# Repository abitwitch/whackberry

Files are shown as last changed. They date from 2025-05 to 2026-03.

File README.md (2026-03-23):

# WhackberryPi
Disconnected Cyberdeck for password management.

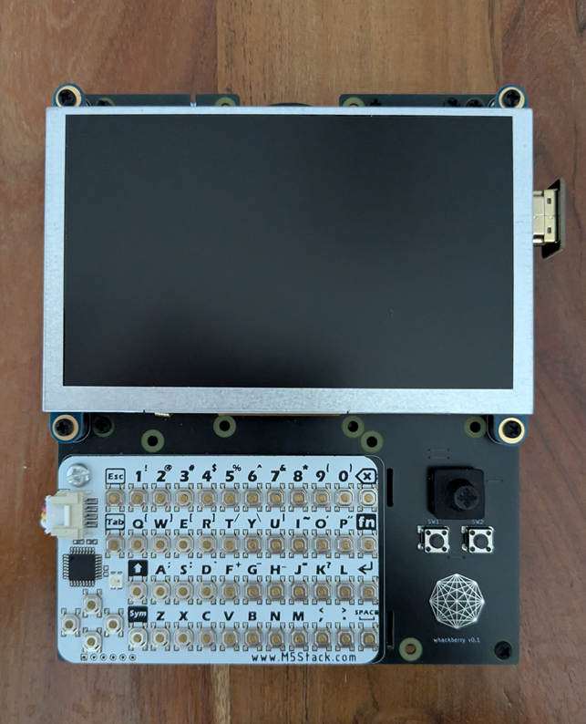
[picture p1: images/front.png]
Front of device

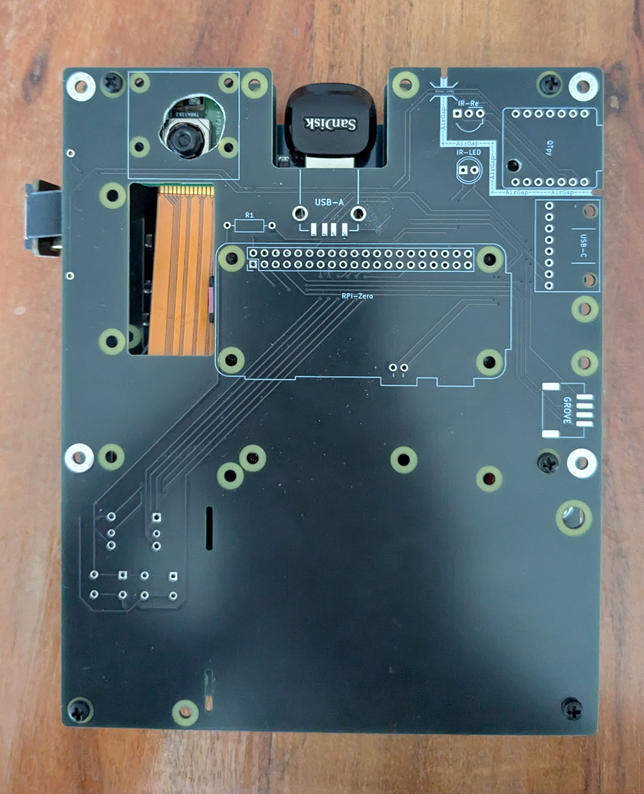
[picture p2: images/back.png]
Back of device


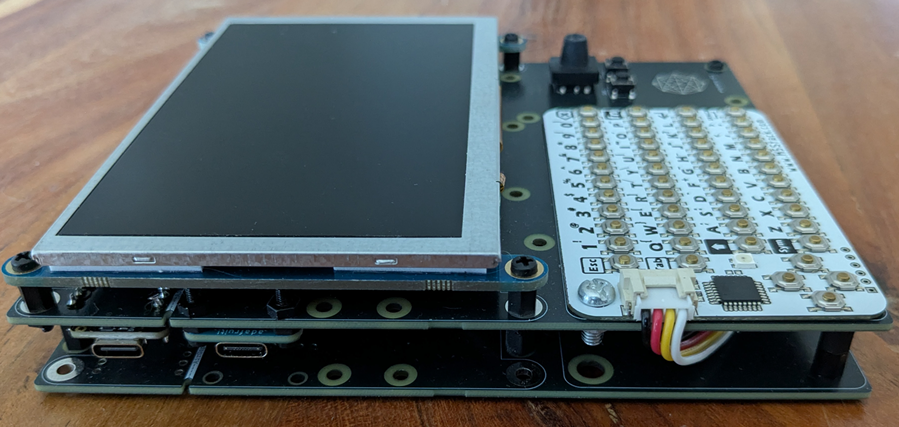
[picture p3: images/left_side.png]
Left side of device

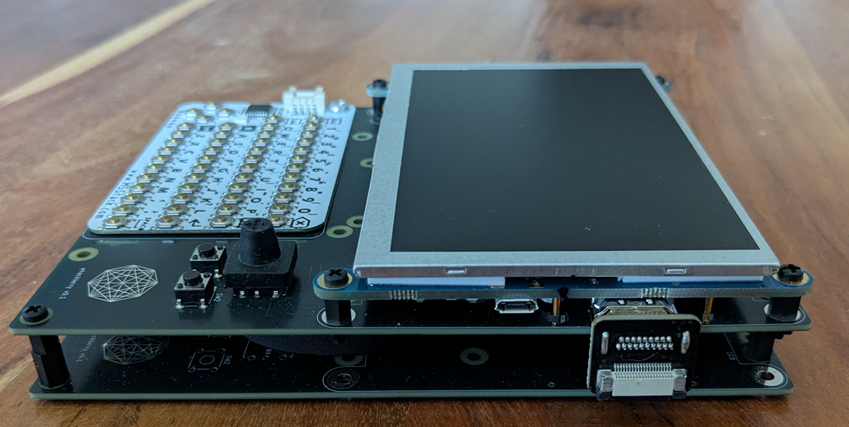
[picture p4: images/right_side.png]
Right side of device


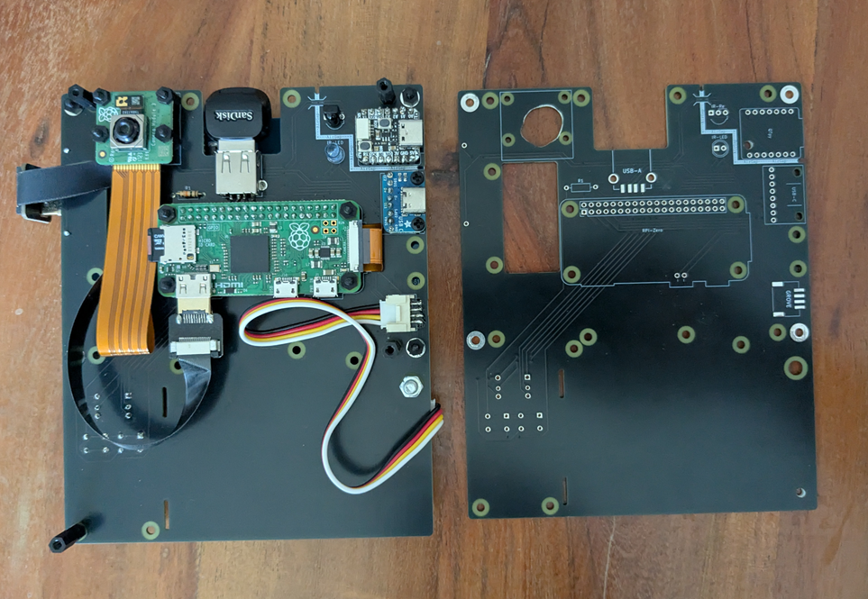
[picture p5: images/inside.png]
Inside of device


## Features:
- Disconnected computer (with display) with no wireless connectivity on any part of the device
- QWERTY keyboard with access to most standard symbols
- A mouse for navigating the OS in GUI mode
- A additional Micro SD card reader that can be used to create backups of passwords for storage in a secure secondary location
- A Camera to take pictures that are unable to reach the internet (useful for QR backup codes of 2FA apps)
- A disconnected microcontroller that is able to transmit data from the disconnected computer to another computer using a data diode

## How the data diode works:
1. The disconnected computer has a special command for transmitting data (`ir-sender`). This program can take standard input in bash.
2. The program encrypts the input. *NOTE* that the hardware only suport very weak and out-of-date encryption. Although it may provide a small layer of security, it should not be relied upon. This means anyone able to read the IR led blinking from inside the case, may be able to eventually decypt the messages. This seems like a low-level risk.
3. The program break the message into packets then into pulses and used the IR LED light transmit the password. Since there is no way to read messages from the LED, this is a one way communication. This is the data diode and it uses the "fire and forget" principle. This means errors in reading the message is possible. A check sum is part of the protocol to account for this possible error.
4. On the other side of the LED there is a IR Reciever. It is connected to a microcontroller that is completely disconnected* from the raspberry PI. The only way to communicate is over the air-gap via IR (one way).
*Note that the microcontroller is connected via power (5v and Ground). This allows the disconnected computer to be powered when the microcontroller is pluged into a computer. This does technically open the possibility of side channel attacks. 
5. The signal is recieved, decapsulated, combined, and de-crypted. The checksum is verified before decryption and the process will only continue if the checksum and decryption are successful.
6. When plugged into a computer, the air-gapped microcontroller acts as a keyboard and the message recieved is transmitted as keystrokes to the computer.

# Setup:
To set up a device, follow the instructions in each section of this readme from top to bottom. 

## Main Hardware
- Raspberry Pi Zero v1.3 [link](https://www.adafruit.com/product/2885)
- M5 CardKB (v1.1)
- HDMI 5" Display [link](https://www.adafruit.com/product/2232)
- Raspberry Pi Camera Module 3 [link](https://www.adafruit.com/product/5657)
- Infrared LED [link](https://www.adafruit.com/product/387)
- Infrared Receiver Sensor [link](https://www.adafruit.com/product/157)
- QT Py RP2040 [link](https://www.adafruit.com/product/4900)
- At least 1 micro CD card
- A Raspberry Pi with internet (for setup only)

## Supporting Hardware and PCB Mounting / cable accessories
- SMD Grove Female Header [link](https://www.mouser.ca/ProductDetail/Seeed-Studio/114020164?qs=7MVldsJ5Uayw%2FOfizq4F8w%3D%3D)
- USB Type-A Jack [link](https://www.mouser.ca/ProductDetail/Amphenol-FCI/87583-0010BHLF?qs=HGI6s9c03KdFNxR4%2F7F3Vg%3D%3D)
- HDMI cable [link1](https://www.adafruit.com/product/3552) [link2](https://www.adafruit.com/product/3549) [link3](https://www.adafruit.com/product/3561)
- Thru-hole 5-way Navigation switch (used as a mouse) [link](https://www.adafruit.com/product/504)
- 2x Buttons [link](https://www.adafruit.com/product/367)
- Pogo pins [link](https://www.adafruit.com/product/5381)
- Stand-off screws (the camera module may require a different size) [link](https://www.adafruit.com/product/3299)
- 1x 10k resistor [link](https://www.adafruit.com/product/2784)
- Male-male pin headers [link](https://www.adafruit.com/product/3009)
- USB Type C Breakout Board [link](https://www.adafruit.com/product/4090)
- SD card reader - SanDisk MobileMate USB 3.0 Reader [link](https://shop.sandisk.com/en-ca/products/accessories/memory-card-readers/sandisk-quickflow-microsd-usb-a-memory-card-reader?sku=SDDR-B731-GN6NN)
- DPDT switch [link](https://www.digikey.ca/en/products/detail/e-switch/EG2208/301963)
- One M4 nut and bolt (to attach CardKB)
- Solder and an soldering iron

## PCB
There PCB (Printed Circuit Board) design is included in this repository. This can be ordered online for a PCB manufacturer. If you want to forgo the case, you can order 2 boards and use the second with the one with standoffs to protect the device. 

**Schematic**
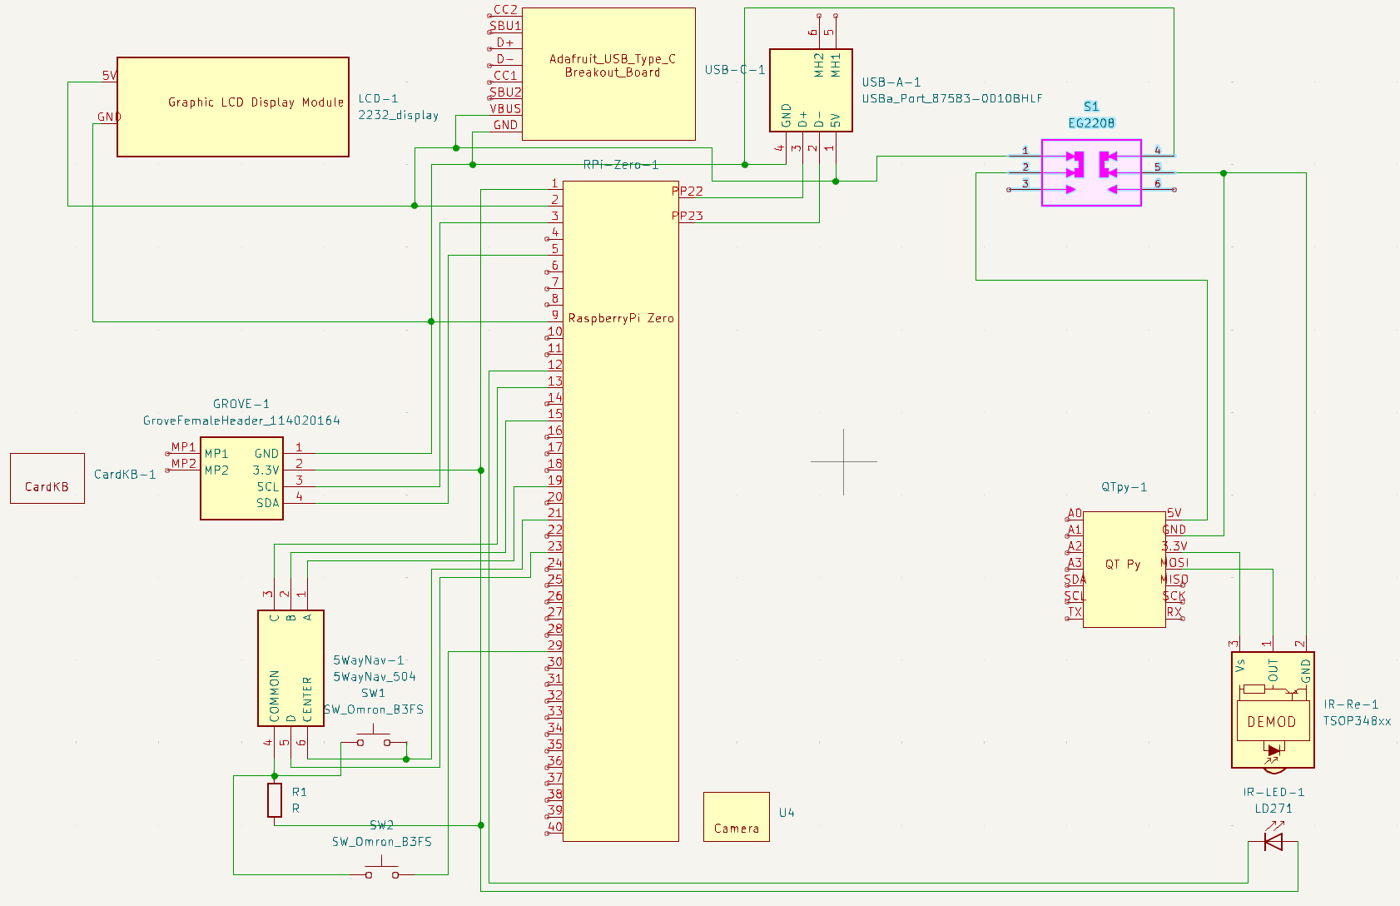
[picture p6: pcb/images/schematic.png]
Schematic showing all connections for the PCB Schematic of the PCB


**Design view**
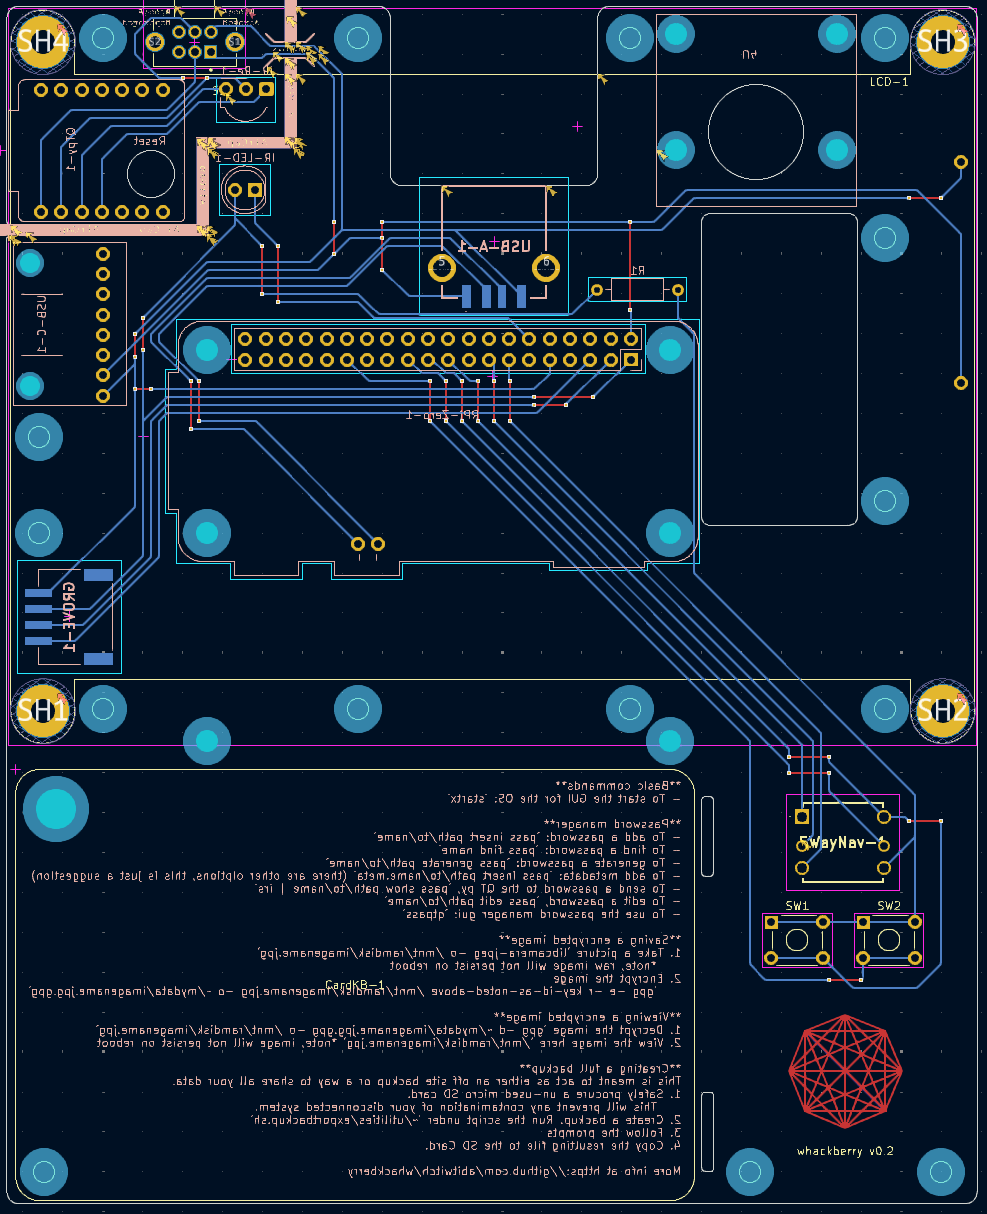
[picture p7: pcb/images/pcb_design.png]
Design view showing all the traces, cuts, and lables for the PCB Design of the PCB


**Front view**
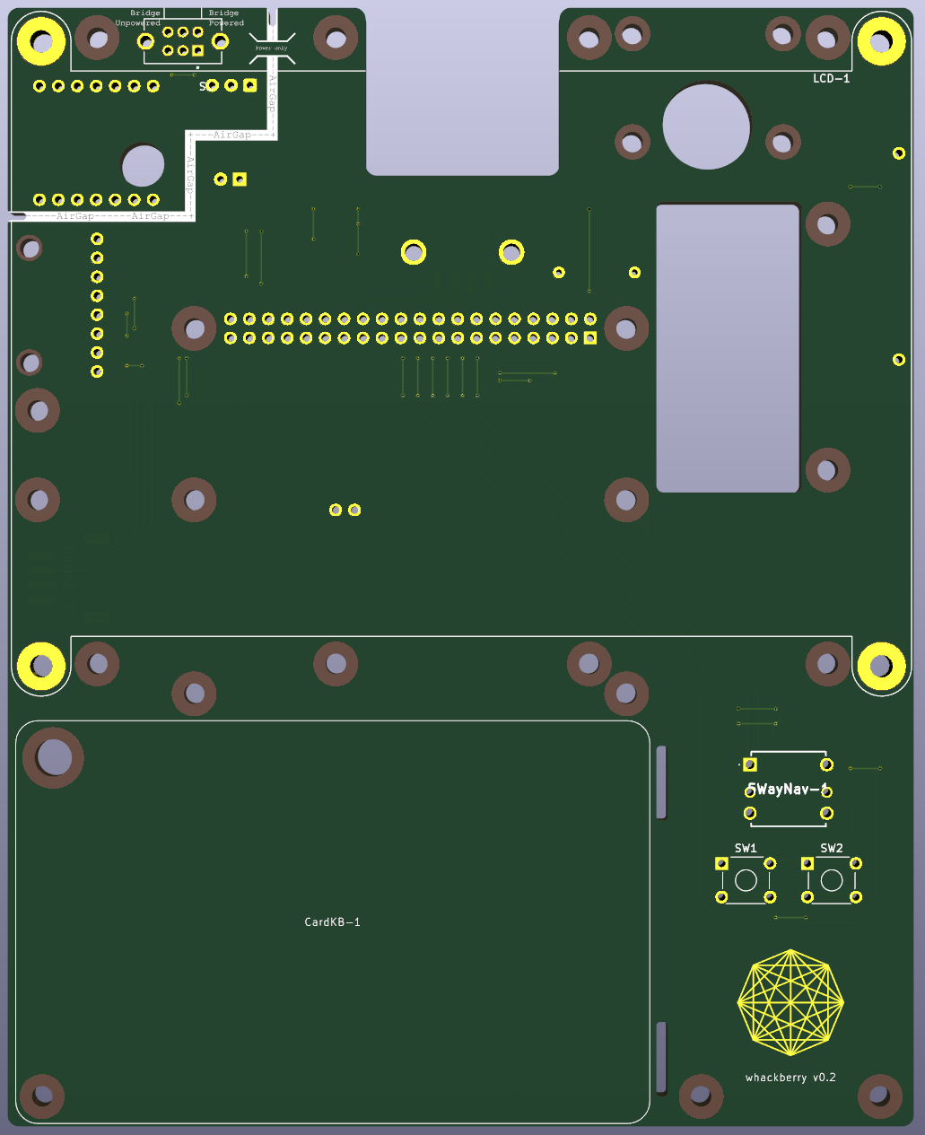
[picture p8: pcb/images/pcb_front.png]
Render of the front of the PCB Front of the PCB


**Back view**
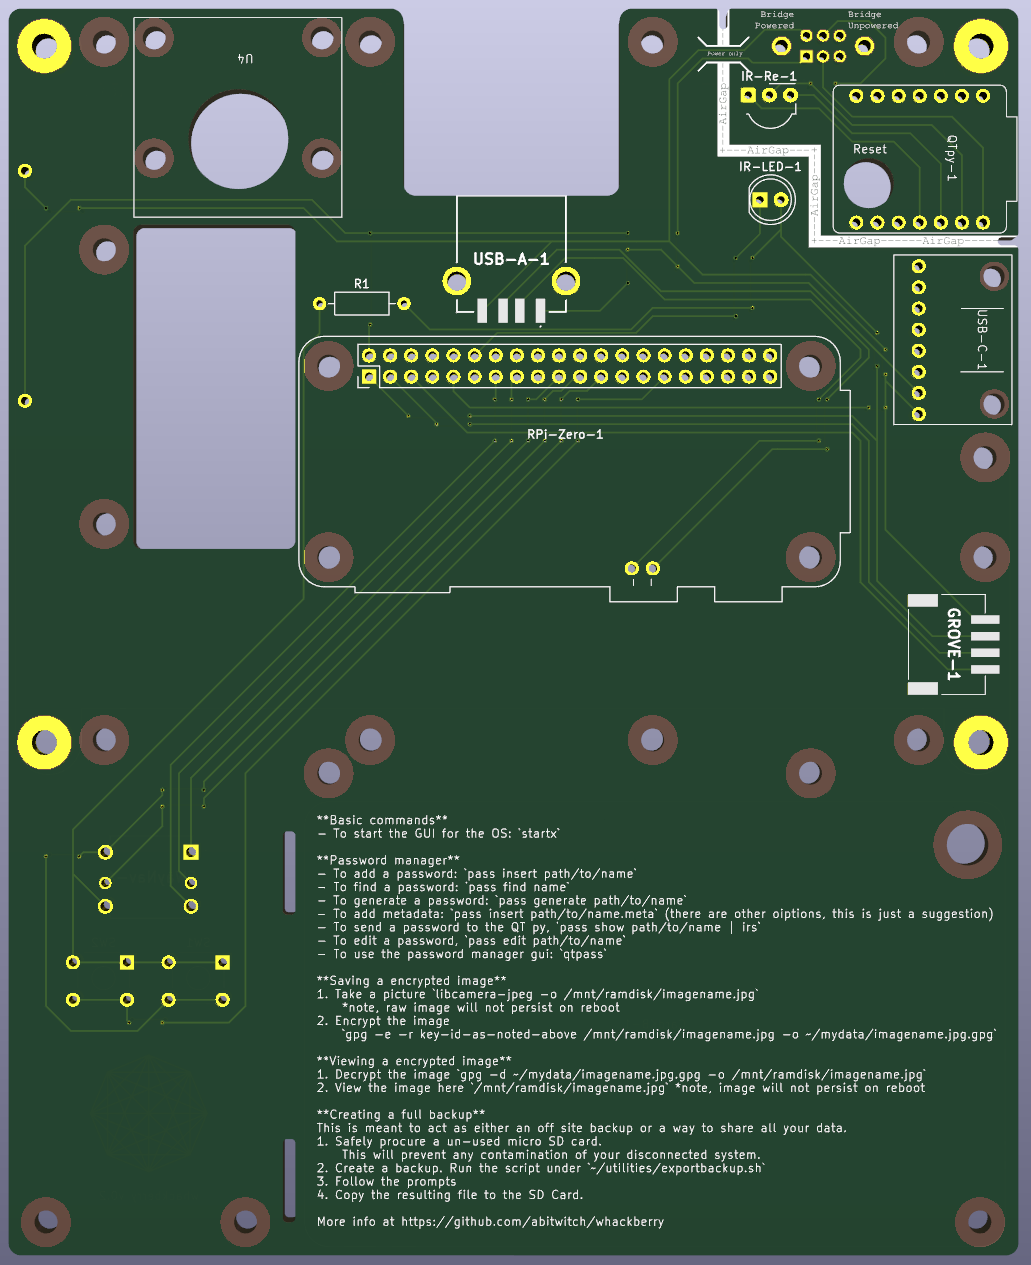
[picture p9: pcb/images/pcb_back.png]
Render of the back of the PCB Back of the PCB


## Assembly guide

This guide assumes you have some experince with soldering. Locational references (up, down, left, right) assume the PCB is upright with the logo facing you. The logo side is the front of the board, the other side is the back. 
### Prepare parts
1. Break the Male-male pin headers into 2 7 pin pieces and 1 8 pin piece
2. Solder the QTpy to the two 7 pin headers with the pins facing away from the side with the USB port on it.
3. Repeat the previous step for the Raspberry Pi Zero, and USB-c Breakout board. 
4. Break the POGO pins into 2 single pins and 1 pieces with 2 still attatched pins.

### Attach USB-c Breakout board
1. Use a M2.5 hex nut as a space between the USB-c breakout board and the main PCB, with the USB-c breakour board on the back of the main PCB. Secure the breakout board in place with more M2.5 nuts and screws
2. Clip of excess pin length from the pins of the USB-c breakout board headers and then solder the pins in place

### Attach QTpy
1. Place the QTpy in place on the back of the main PCB
2. Clip of excess pin length from the pins of the QTpy headers and then solder the pins in place

### Attach Raspberry Pi Zero
1. Solder the 2 attached pogo pins below the main headed pins in the Raspberry Pi Zero footprint. The pins should be facing the back of the board
2. Use 6mm long F-F hex standoffs and screws to attach the Raspberry Pi Zero fo the back of the main PCB. The pogo pins should be making contect with the Raspberry Pi Zero, and the main header pins should slightly protrude through the main PCB. 
3. Solder all the main header pins into place.

### Other soldered-in pieces
1. Solder the GROVE Female Header onto the back of the main PCB
2. Solder the USB Type-A Jack onto the back of the main PCB
3. Insert the 5-way nav switch on the front of the PCB and solder in the pins
4. Repeat step above for both buttons below the 5-wav nav switch
5. Insert the Resistor on the back of the main PCB, clip excess pin lenth, and solder into place
6. Repeat step above for the IR-Reciever and the IR LED

### Attach the camera module
1. The mounting holes on the camera module are slightly smaller than M2.5 screws. You will either need to largen the holes are buy different hardware.
2. Use 6mm long F-F hex standoffs to attatch the camera to the back of the main PCB

### Attach CardKB
1. Use the M4 nut and bolt to attach the CardKB to the front of the main PCB

### Cables
1. Connect the Camera module to the Raspberry Pi Zero
2. Connect the CardKB to the main PCB GROVE header
3. Use the DYI HDMI cable to connect the display to the Raspberry Pi Zero

### Protection plate
Only do this if you are not making a 3D printed case
1. Choose 4 or 5 well distributed, unused, and accessible mounting holes and insert into each a M2.5 10mm Screw into an unused PCB (with nothing else solder or attached to it)
2. To the back of each of the screws, screw on a 6mm long F-F hex standoff untill snug
3. To the still protruding screws, screw on a 8mm long F-F hex standoff untill snug
4. Place the this PCB on the main on being careful not to pitch any cables
5. Screw the two boards together with M2.5 4mm Screws into the standoffs

## Setup guide

### 1.00: SD card setup
This part can be done on any trusted computer connected to the internet
1. Download Official Raspberry Pi Imager
2. Select Legacy, 32-bit - Debian Bullseye (released 2024-10-22)
3. Flash the SD card and then access the files on the SD card
4. Set up the display
   1. Setup the display. Under `bootfs > config.txt` if accessing from a SD Card reader or `\boot\config.txt` if accessing from the OS, add the following lines (more info [here](https://learn.adafruit.com/adafruit-5-800x480-tft-hdmi-monitor-touchscreen-backpack/raspberry-pi-config))
       ```
       hdmi_group=2
       hdmi_mode=87
       hdmi_cvt=800 480 60 6 0 0 0
       hdmi_drive=1
       max_usb_current=1
       ```
   2. Enable i2c. In the same `config.txt` file, uncomment "dtparam=i2c_arm=on". Follow instructions [here](https://raspberrypi.stackexchange.com/questions/83457/can-i-enable-i2c-before-first-boot)

### 2.00: Configure the OS
I suggest doing the configuartion from another pi with internet. Plug the SD card into a internet-connected Raspberry Pi and boot it. Follow the commands to set up your account and apply any updates. You can use a less secure password if you want, the more import one will be the one you use when setting up a GPG key. Reboot the device.

#### 2.01: Enable i2c
1. In terminal type, `sudo raspi-config`
2. `Interface Options > I2C > Yes  (enable) > OK > Finish`

#### 2.02: Turn on boot to terminal by default (optional)
1. In terminal type, `sudo raspi-config`
2. `System Options > Boot / Auto login > Console Autologin > Finish`
3. In subsequent boots, if you want a GUI, enter `startx` into the terminal

#### 2.03: Updrade all apps / install new apps
1. In teminal: `sudo apt update && sudo apt full-upgrade`
2. Install password manager `sudo apt-get install pass`
3. Install password manager GUI `sudo apt-get install qtpass`
4. Install a game (helpful for using the system to build up randomness) `sudo apt-get install ninvaders`
5. Install 7z for secure ziped exports: 'sudo apt-get install p7zip-full'
6. Install circuit python: `sudo pip3 install adafruit-blinka`
7. Install PyUserInput for mouse: `sudo pip3 install PyUserInput pynput`
8. Install web3 for ethereum wallet generation: `sudo pip3 install web3`

#### 2.04: Install Electum
1. Go to [https://electrum.org/#download](https://electrum.org/#download)
2. `mkdir ~/electrum`, then `cd ~/electrum`
3. Follow the instructions for "Installation from Python sources" (tested with version 4.5.8)

#### 2.05: Copy Etherium wallet script
1. `mkdir ~/cryptowallet`
2. Copy `cryptowallet/gen-eth-wallet.py` from this repo to `~/cryptowallet/gen-eth-wallet.py` on the raspberry pi
3. `chmod +x gen-eth-wallet.py`

#### 2.06: CarKB setup
1. `mkdir ~/cardkb`, then `cd ~/cardkb`
2. Follow instructions [here](https://github.com/ian-antking/cardkb) (Note: add `sudo` to `modprobe uinput`)

#### 2.07: Camera Setup
- Just plug and play
- `libcamera-hello` to test
- `libcamera-jpeg -o /path/to/file.jpg` to take a picture

#### 2.08: Set up 5-way navi mouse
1. `mkdir ~/navmouse`, then `cd ~/navmouse`
2. Copy `navmouse/mouse.py` and `navmouse/navmouselauncher.sh` from this repo to `~/navmouse` on the raspberry pi
3. `chmod +x *`
4. 'sudo nano /etc/xdg/lxsession/LXDE-pi/autostart`
5. Add this line to the end of the file, then save and exit: `@/home/{name of user}/navmouse/navmouselauncher.sh`
TODO: Fix this section

#### 2.09: Infrared Transmitter
1. Create a RAM disk for storing output:
   1. Add `newramdisk  /mnt/ramdisk  tmpfs  rw,size=8M  0  0` to `/etc/fstab` (*Note, you must replace each set of spaces with a tab*)
2. Configuration
   1. `sudo nano /boot/config.txt`
   2. Add a line with `dtoverlay=gpio-ir-tx,gpio_pin=18` to the file, then save and exit
   3. `sudo nano /etc/modules`
   4. Add a line with `lirc_dev` to the file, then save and exit
3. `mkdir ~/ir-sender`
4. Copy `ir-protocol/ir-sender` from this repo to the folder `~/ir-sender`
5. Copy `ir-protocol/ir-sender-gui` from this repo to the folder `~/Desktop/ir-sender-gui`
6. `chmod +x ~/ir-sender`
7. `chmod +x ~/Desktop/ir-sender-gui`
8. Add these lines `~/.profile`
   ```
   if [ -d "$HOME/ir-sender" ] ; then
   PATH="$PATH:$HOME/ir-sender"
   fi
   ```
9. Generate new key: `ir-sender --genkey`
10. Copy the contents of the json and use it when setting up the Infrared Reciever
11. For ease of use, add an alias for `ir-sender`
   1. Edit `~/.bashrc`
   2. Add this line to the bottom: `alias irs=ir-sender`

#### 2.10: Infrared Reciever
This part of the device is on an isolated device that emulates a keyboard when plugged into the computer.
On a PC connected to the Pico
1. Download circuit python for the QTPy RP2040 ([link](https://circuitpython.org/board/adafruit_qtpy_rp2040/)) (I used CircuitPython 9.2.6)
2. Download the circuit python bundle ([link](https://github.com/adafruit/Adafruit_CircuitPython_Bundle/releases/tag/20250319)) (I used 'March 19, 2025 auto-release')
3. While holding down the `BOOT` button on the QTPy, connect it to the PC.
4. Copy the "uf2" file you downloaded in step 1 to the device. You should see `INDEX.HTM` and `INFO_UF2.TXT` there already. Wait for the device to reboot.
5. Unzip the folder from step 2 and copy the following folders and file to the `lib` folder of the QTPy.
   `adafruit_hid`, `adafruit_pixelbuf.mpy`, `neopixel.mpy`, `adafruit_rsa`, `adafruit_logging.mpy`, `adafruit_binascii`, `adafruit_hashlib` 
8. Copy the contents of the `ir-receiver-code.py` to `code.py`
9. Copy `boot.py` to `boot.py` at the top level of the QTPy
10. Create a new file at the top level called `private_key.json` and put the json contents in it generated when setting up the Infrared Transmitter

Optional: If you want a second reciever for any reason (for example, you don't want to plug the same reciever into every computer you need a password on), here's how to set up a secondary one.
1. Buy a secondary RP2040 device. This guide will assume you're using [the Waveshare RP2040-One](https://www.waveshare.com/product/rp2040-one.htm).
2. Solder on a IR (Infrared) Receiver (the same one listed earlier in this project). Attach GND to GND, V to 3.3V, and OUT to GP0. 
3. Follow the same steps above (for the main Infrared Reciever), with these minor changes
   1. In the `code.py` file, change `board.MOSI` to `board.GP0` and `board.NEOPIXEL` to `board.GP16`
   2. In the `boot.py` file, change `board.A0` to `board.GP15`
   3. Copy the `private_key.json` from the original RP2040 device to this one

#### 2.11: Copy over the utility scripts
1. `mkdir ~/utilities`
2. Copy `utilities/exportbackup.sh` from this repo to `~/utilities/exportbackup.sh` on the raspberry pi
3. Copy `utilities/importfromcsv.py` from this repo to `~/utilities/importfromcsv.py` on the raspberry pi
4. `sudo chmod +x ~/utilities/*`

#### 2.12: Test the system
1. Power down the raspberry pi you're using for setup. Move the SD card to the offline raspberry pi. 
2. Test the system to make sure all features work as expected

#### 2.12: Copy any passwords to the SD card
Copy password from any existing password managers to the SD Card (make sure to place them in a appropriate folder as not to mess up the OS on the SD Card).

### 3.00: Finish system init (offline) 
Only perform these steps when you're done setting up the device and ready to never connected to the internet again
1. If the SD card is still in the Raspberry Pi you were using for setup, move it to the offline Raspberry Pi Zero. 
2. Use system for 5-10 minutes to generate entopy (try `ninvaders`)
3. `mkdir ~/mydata`
4. Set up password manager
   1. Generate key
      1. `gpg --gen-key`
      2. Real name: user
      3. Email: [empty]
      4. `O` for okay
      5. Enter a password (this will be the master password for the password manager). Make sure it is a secure password and do not share it. 
      6. Note the id of the key. This will be a lond alphanumberic sequence right above "uid"
   2. Set key to never expire
      1. `gpg --edit-key key-id-as-noted-above`
      2. `expire`
      3. enter `0`
      4. `q` to quit (and `y` to save changes)
   2. `pass init key-id-as-noted-above`
5. Generate Bitcoin BTC wallet
   1. Start electrum with this command `~/electrum/Electrum-4.5.8/run_electrum`
   2. This application will run slowly. Be prepared to wait a few minutes between screens.
   3. Follow prompts and be sure to save the new seed to the password manager (`pass`). Using a password is recommended, you can generate and store one it `pass`, then copy it to the clipboard by using `pass -c {Folder/name}`
   4. In the "Recieve" tab, create a never expiring request and save the public address to `pass` as well. You can use this to send money to the wallet.
   5. Export the private keeys to `pass`
      1. Under "Wallet" > "Private keys", select "Export"
      2. Specify the file location to somewhere on `/mnt/ramdisk` (this way it will not presist on disk as plain text)
      3. Add a column to the CSV titled "BurntPrivKey", and set it to "No" for all rows
      4. Run `cat /mnt/ramdisk/{filename-of-exported-keys.csv} | pass insert {Folder/name} -m`
6. Generate Etherium ETH wallet
   1. Run the command `python3 ~/cryptowallet/gen-eth-wallet.py`
   2. Enter both the private key and the public key to the `pass` password manager

## Using the system
**Basic commands**
- To start the GUI for the OS: `startx`

**Password manager**
- To add a password: `pass insert path/to/name`
- To find a password: `pass find name`
- To generate a password: `pass generate path/to/name`
- To find a password: `pass find myaccount`
- To add metadata: `pass insert path/to/name.meta` (there are other oiptions, this is just a suggestion)
- To send a password to the QT py, `pass show path/to/name | irs`
- To edit a password, `pass edit path/to/name`
- To use the password manager gui: `qtpass`

**Saving a encrypted image**
1. Take a picture `libcamera-jpeg -o /mnt/ramdisk/imagename.jpg` *note, raw image will not persist on reboot
2. Encrypt the image `gpg -e -r key-id-as-noted-above /mnt/ramdisk/imagename.jpg -o ~/mydata/imagename.jpg.gpg`

**Viewing a encrypted image**
1. Decrypt the image `gpg -d ~/mydata/imagename.jpg.gpg -o /mnt/ramdisk/imagename.jpg`
2. View the image here `/mnt/ramdisk/imagename.jpg` *note, image will not persist on reboot

**Creating a full backup**
This is meant to act as either an off site backup or a way to share all your data.
1. Safely procure a un-used micro SD card. This will prevent any contamination of your disconnected system.
2. Create a backup. Run the script under `~/utilities/exportbackup.sh`
3. Follow the prompts. Note that with a lot of passwords, the "Exporting passwords" step can take a long time to run (last time was ~30 minutes for me).
4. Copy or move the resulting file to the SD Card.

**Import csv to password manager**
1. Modify the script here: `~/utilities/importfromcsv.py` to match the fields in the CSV from your password manager
2. Run `python3 ~/utilities/importfromcsv.py /path/to/passwords.csv`
3. After successfully importing the passwords, delete the csv `rm /path/to/passwords.csv`

## Sending recieving Bitcoin (btc)
You can send and recieve btc without exposing your private keys to the internet.

### Recieving:
1. Open Electrum
2. Go to the recieving tab and create a request. Make one of your "burnt" addresses it not being used. Send btc using any app to that address.

### Sending:
Option 1: signing a transaction (requires manual transcription)
1. On a computer connected to the internet
   1. Install Electrum and wait for it to sync
   2. Go to File > New/Restore
   3. Select "Import Bitcoin addresses or private keys"
   4. Enter the public addess (NOT the private keys!) from the Whackberry device (you can do that using this command: `echo bitcoin_public_address | irs`)
   5. Under the send tab, enter the address you want to send to, the amount, then click "Pay..."
   6. Set the transation fee and click "OK"
   7. Click the share button and "Copy to clipboard..." (paste in a text editor)
2. On the Whackberry
   1. Open Electrum
   2. On the top menu, "Tools" > "Load transation" > "From text"
   3. The camera will not work with the Electrum app, so you will have to manually copy the transation to the whackberry (make no mistakes, good luck).
   4. "Sign" the transation
   5. Click the share button and "Copy to clipboard..." (recommend pasting it somewhere like `/mnt/ramdisk/txn.txt`)
   6. Transfer that file back to the internet connected computer: `cat /mnt/ramdisk/txn.txt | irs` (you'll want to open a text editor on the internet connected computer to capture the contents of the file) 
3. On a computer connected to the internet
   1. In Electrum, on the top menu, "Tools" > "Load transation" > "From text"
   2. Paste in the transation contents you transfered from the whackberry.
   3. Click "Broadcast"
Option 2: Burning a Private key
1. Mark the private key as "burnt" on the Whackberry: `pass edit path/to/privatekeys`. I recommend labeling it in the Electrum GUI too (under the addresses tab)
2. Copy the ONLY THE BURNT private keys to a internet connected computer
   1. Test a command to ONLY get the burnt addresses: `pass show path/to/privatekeys | grep ,Yes` (Make 100% sure it's only outputing the private keys you want to burn)
   2. Copy the ket to the internet connected computer: ``pass show path/to/privatekeys | grep ,Yes | irs`
3. On the internet connected computer
   1. Follow steps 1.1 to 1.3 under "Option 1"
   2. Enter the private key
   3. Transfer all the bitcoin to your intended addresses. Keep in mind you can also transfer to other addresses on the Whackberry that are not yet burnt.

## Accessing cold wallets (online) 
1. Use `ir-sender` to send the target private key from the disconnected raspberry pi to a computer connect to the internet. Make sure to note any private keys or seeds being transfered. They are no longer totaly secure.
2. For Bitcion BTC:
   1. Download and install the Electrum application. Be very careful to download from the offical page (https://electrum.org/#download)[https://electrum.org/#download]
   2. Open the application and when prompted, select "Standard wallet" then "I already have a seed"
   3. Enter the seed for the Bitcoin BTC wallet.
   4. You can use the "Send" tab to send to any address. Start with a small amount to make sure everything is working.
3. For Etherium ETH:
   1. You can use any wallet that supports importing private keys to access the BTC. I'll include instructions for MetaMask Firefox Extension (v12.6.2) below.
   2. Go to MetaMask's site. Be sure it's the official source: [https://metamask.io/download/](https://metamask.io/download/)
   3. Download and lauch the extension
   4. Follow the propmts and select "create new wallet"
   5. Once on the main account page, click the account dropdown at the top of the screen
   6. Select "Add account or hardware wallet" then "Import account"
   7. Enter the private key for Etherium ETH.
   8. You can use the "Send" button to send to any address. Start with a small amount to make sure everything is working.

## Case
There is a 3D printable case included in this repository to help manage the cables and protect the devices. This case is yet to be printed and tested, so it likely we need to be altered and iterated. 

**Front of case**
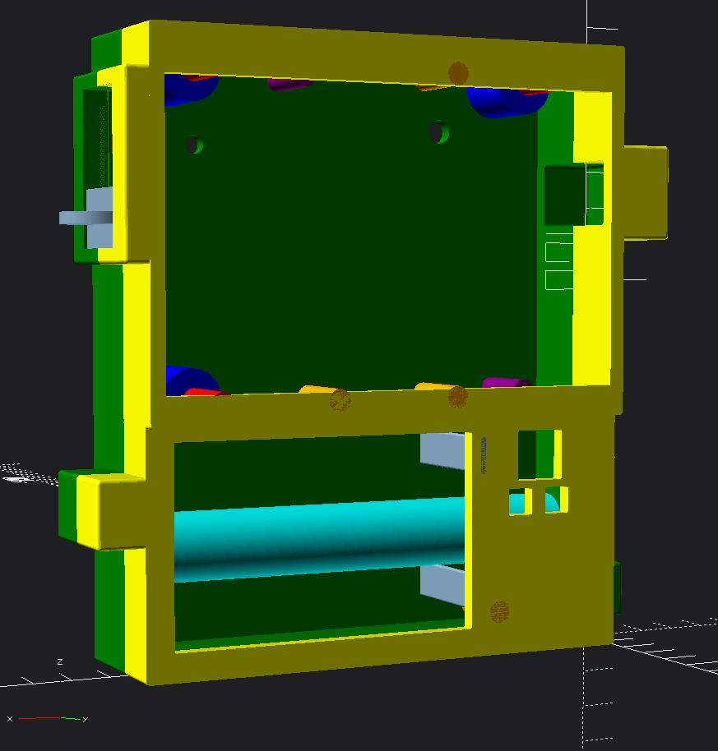
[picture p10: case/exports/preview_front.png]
3D render of the front of the case Front of case


**Back of case**
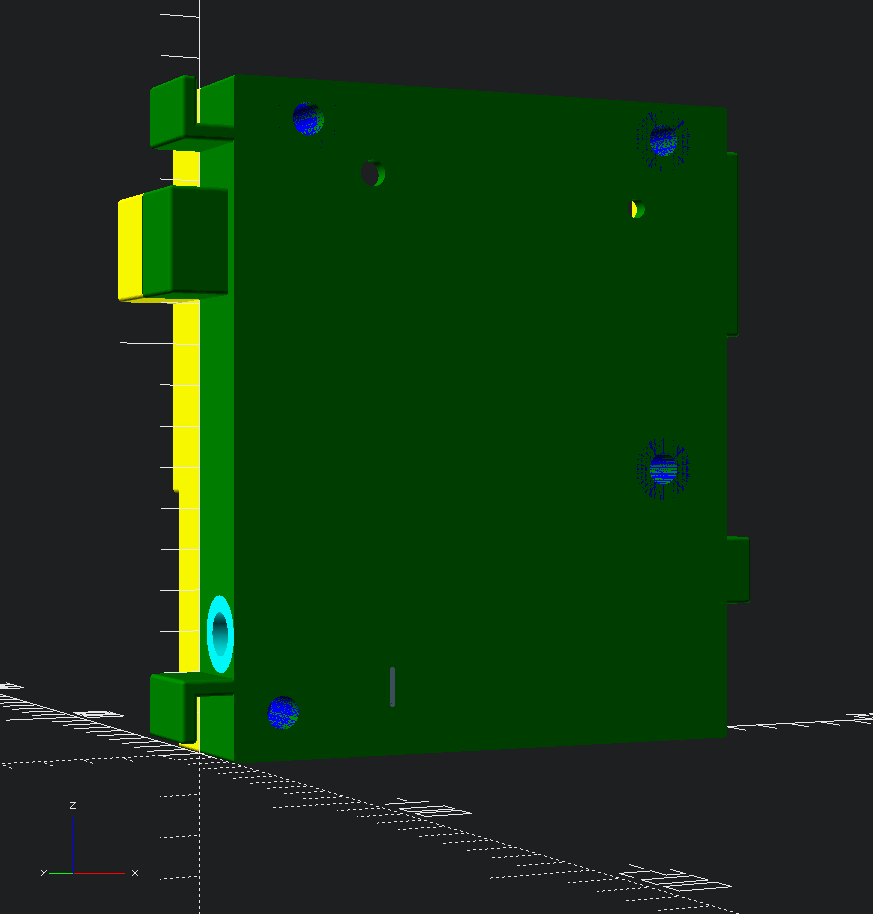
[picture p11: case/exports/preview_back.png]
3D render of the back of the case Back of case


## Trouble shooting
- Opening the camera causes the system to crash
   - This is likely a power issue to the camera. First try adding these two lines to the "/boot/config.txt" file; `over_voltage=2` and `force_turbo=1`. If the problem persists, lower the blacklight one the display by cutting the trace in between the two pads labeled "Open for -25mA" (more info [here](https://learn.adafruit.com/adafruit-5-800x480-tft-hdmi-monitor-touchscreen-backpack/pinouts)).

## Future work
- setup HID to act as a security key
- fix tempermental QTpy

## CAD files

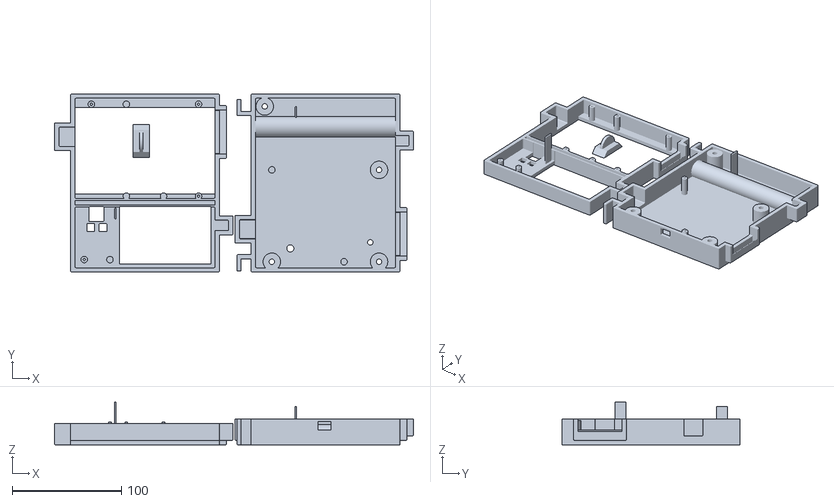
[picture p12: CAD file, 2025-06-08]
case/exports/case.stl
328.2 x 163.0 x 39.0

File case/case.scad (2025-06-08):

include <./modules/roundedcube.scad>
include <./modules/slider.scad>
include <./modules/screwhole.scad>
include <./modules/holepeg.scad>
//Note objects are anchored to the bottom right corner

//Vars (UNITS = mm)
global_thickness=4;
global_gap=3.5;
global_gap_tight=1.5;
global_nudge=0.01; //used as a tiny push to prevent two shapes from overlapping in digital rendering
global_pcb_thickness=1.4;
outer_upper_height=92+global_thickness+global_gap;
outer_upper_width=121+(2*global_thickness)+(2*global_gap);
outer_upper_depth=12+global_thickness+global_gap;
outer_upper_rounding=1;
outer_lower_height=56+global_thickness+global_gap;
outer_lower_width=outer_upper_width;
outer_lower_depth=8+global_thickness+global_gap;
outer_lower_rounding=outer_upper_rounding;
outer_rear_depth=16+global_thickness+global_gap;
keyboard_height=52.5;
keyboard_width=84;
keyboard_offset=[outer_lower_width-keyboard_width-global_thickness-global_gap,0,global_thickness+global_gap];
keyboard_rounding=0.5;
keyboard_bump_rounding=1;
keyboard_bump_height=10+global_thickness+global_gap;
keyboard_bump_width=5+global_thickness+global_gap+outer_lower_rounding+keyboard_bump_rounding;
keyboard_bump_depth=outer_lower_depth;
keyboard_bump_offset=[outer_lower_width-outer_lower_rounding-keyboard_bump_rounding,0,34];
keyboard_bump_hollow_offset=[keyboard_bump_offset[0]+global_thickness,keyboard_bump_offset[1]-global_nudge,keyboard_bump_offset[2]+global_thickness];
keyboard_support_front_width=1.4;
keyboard_support_front_depth=outer_lower_depth+outer_rear_depth-global_thickness;
keyboard_support_front_height=9.9;
keyboard_support_front_rounding=keyboard_support_front_width/2;
keyboard_support_front_offset=[32.8+global_thickness+global_gap,outer_lower_depth-keyboard_support_front_depth,41.1+global_thickness+global_gap];
keyboard_support_rear_width=keyboard_support_front_width;
keyboard_support_rear_depth=keyboard_support_front_depth;
keyboard_support_rear_height=keyboard_support_front_height;
keyboard_support_rear_rounding=keyboard_support_front_rounding;
keyboard_support_rear_offset=[32.8+global_thickness+global_gap,outer_lower_depth-keyboard_support_front_depth-global_thickness,4.1+global_thickness+global_gap];
mouse_nav_height=13.5;
mouse_nav_width=13.5;
mouse_nav_offset=[9.4+global_thickness+global_gap,0,38.8+global_thickness+global_gap];
mouse_nav_rounding=0.5;
mouse_left_height=7.2;
mouse_left_width=7.2;
mouse_left_offset=[18.5+global_thickness+global_gap,0,29.6+global_thickness+global_gap];
mouse_left_rounding=0.5;
mouse_right_height=mouse_left_height;
mouse_right_width=mouse_left_width;
mouse_right_offset=[7.3+global_thickness+global_gap,0,29.6+global_thickness+global_gap];
mouse_right_rounding=mouse_left_rounding;
display_height=75.9+(2*global_gap_tight);
display_width=121+(2*global_gap);
display_offset=[global_thickness,0,65.6+global_thickness+global_gap-global_gap_tight];
//display_rounding=0.1;
display_bump_rounding=1;
display_bump_height=18.5+(2*global_gap);
display_bump_width=11.2+global_gap+outer_upper_rounding+display_bump_rounding;
display_bump_depth=outer_upper_depth;
display_bump_offset=[-display_bump_width+outer_upper_rounding+display_bump_rounding,0,107-global_gap+global_thickness+global_gap];
display_bump_hollow_offset=[display_bump_offset[0]+global_thickness,display_bump_offset[1]-global_nudge,display_bump_offset[2]+global_thickness];
usbc_bump_rounding=1;
usbc_bump_height=41.2+(2*global_gap);
usbc_bump_width=3+global_gap+outer_upper_rounding+usbc_bump_rounding;
usbc_bump_depth=outer_upper_depth;
usbc_bump_offset=[outer_upper_width-outer_upper_rounding-usbc_bump_rounding,0,100-global_gap+global_thickness+global_gap];
usbc_bump_hollow_offset=[usbc_bump_offset[0]+(global_thickness*0),usbc_bump_offset[1]-global_nudge,usbc_bump_offset[2]+global_thickness]; //(global_thickness*0) to make is 2x thickness
slider_panel_width=20;
slider_panel_depth=6;
slider_panel_height=15;
slider_track_width=5;
slider_offset=[outer_upper_width,-(slider_panel_width+(2*slider_track_width))/2,usbc_bump_offset[2]+global_thickness];
slider_hollow_growth_factor=1.10;
slider_hollow_y_offset=-(((slider_panel_width*slider_hollow_growth_factor)+(2*slider_track_width*slider_hollow_growth_factor))-(slider_panel_width+(2*slider_track_width)))/2;
screwhole_radius=2.2/2;
screwhole_support_radius=3;
screwhole_nudge=global_nudge;
screwhole_offsets=[ //lateral offsets are to center of screwholes
  [5+global_thickness+global_gap,0,4+global_thickness+global_gap],
  [11.5+global_thickness+global_gap,0,146+global_thickness+global_gap],
  [109.5+global_thickness+global_gap,0,146+global_thickness+global_gap],
  [109.5+global_thickness+global_gap,0,62+global_thickness+global_gap],
];
//holepeg_support_height=outer_upper_depth;
holepeg_peg_height=global_pcb_thickness;
holepeg_peg_radius=1.2;
holepeg_support_radius=3;
holepeg_offsets=[ //lateral offsets are to center of screwholes
  [28.5+global_thickness+global_gap,0,4+global_thickness+global_gap],
  [43.5+global_thickness+global_gap,0,146+global_thickness+global_gap],
  [43.5+global_thickness+global_gap,0,62+global_thickness+global_gap],
  [77.5+global_thickness+global_gap,0,62+global_thickness+global_gap],
];
holepeg_rear_offsets=[ //lateral offsets are to center of screwholes
  [77.5+global_thickness+global_gap,0,146+global_thickness+global_gap],
  [11.5+global_thickness+global_gap,0,62+global_thickness+global_gap],
];
screwhole_counterbore_radius=4;
screwhole_counterbore_radius_primary=2.5;
pqty_reset_button_hole_radius=2.5;
pqty_reset_button_hole_offset=[101.5+global_thickness+global_gap,0,128.3+global_thickness+global_gap];
camera_hole_radius=3.25;
camera_hole_offset=[28.4+global_thickness+global_gap,0,133.8+global_thickness+global_gap];
sd_slot_offset=[53.8+global_thickness+global_gap,2.1,outer_upper_height+outer_lower_height-global_thickness-global_nudge];
sd_slot_width=12;
sd_slot_depth=8;
cable_hook_strut_length=13;
cable_hook_saddle_length=15;
cable_hook_rounding=1;
lower_cable_hook_offset=[0,-20,0];
upper_cable_hook_offset=[-outer_rear_depth,147,0];
screwdriver_slot_radius=(outer_rear_depth-(2*global_thickness)-(2*global_nudge)-global_pcb_thickness-global_gap)/2;
screwdriver_slot_offset=[0,outer_rear_depth-screwdriver_slot_radius-global_thickness-global_nudge,30];


//Layout Config
layout_printmode=0; //For design layout, set this to 0, for print layout, set to 1
layout_front_rotate=[270*layout_printmode,0,0];
layout_front_offset=[0,0,outer_upper_depth*layout_printmode];
layout_back_rotate=[90*layout_printmode,0,0];
layout_back_offset=[165*layout_printmode,(outer_upper_height+outer_lower_height)*layout_printmode,outer_rear_depth*layout_printmode];
layout_slider_rotate=[0,270*layout_printmode,0];
layout_slider_offset=[180*layout_printmode,120*layout_printmode,-slider_offset[0]*layout_printmode];


//slider
translate(layout_slider_offset)
rotate(layout_slider_rotate)
union () {
  translate(slider_offset)
  //translate([0,0,$t*slider_panel_height]) //animation
  rotate(90,[0,0,1])
  slider(slider_panel_width,slider_panel_depth,slider_panel_height,slider_track_width);
}
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

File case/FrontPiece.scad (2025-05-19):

include <./modules/roundedcube.scad>
include <./modules/slider.scad>
include <./modules/screwhole.scad>
include <./modules/holepeg.scad>
//Note objects are anchored to the bottom right corner

//Vars
global_thickness=0.2;
global_nudge=0.01; //used as a tiny push to prevent two shapes from overlapping in digital rendering
global_pcb_thickness=0.2;
outer_upper_height=8;
outer_upper_width=11;
outer_upper_depth=2;
outer_upper_rounding=0.25;
outer_lower_height=5;
outer_lower_width=outer_upper_width;
outer_lower_depth=1;
outer_lower_rounding=outer_upper_rounding;
keyboard_height=4;
keyboard_width=7;
keyboard_offset=[outer_lower_width-keyboard_width-0.5,0,0.5];
keyboard_rounding=0.5;
keyboard_bump_rounding=0.1;
keyboard_bump_height=1;
keyboard_bump_width=0.5+outer_lower_rounding+keyboard_bump_rounding;
keyboard_bump_depth=outer_lower_depth;
keyboard_bump_offset=[outer_lower_width-outer_lower_rounding-keyboard_bump_rounding,0,3];
keyboard_bump_hollow_offset=[keyboard_bump_offset[0]+global_thickness,keyboard_bump_offset[1]-global_nudge,keyboard_bump_offset[2]+global_thickness];
mouse_nav_height=1;
mouse_nav_width=1;
mouse_nav_offset=[1.5,0,3];
mouse_nav_rounding=0.1;
mouse_left_height=0.5;
mouse_left_width=0.5;
mouse_left_offset=[2.1,0,2.3];
mouse_left_rounding=0.1;
mouse_right_height=mouse_left_height;
mouse_right_width=mouse_left_width;
mouse_right_offset=[1.2,0,2.3];
mouse_right_rounding=mouse_left_rounding;
display_height=6;
display_width=10;
display_offset=[0.5,0,6];
//display_rounding=0.1;
display_bump_rounding=0.1;
display_bump_height=1.5;
display_bump_width=0.5+outer_upper_rounding+display_bump_rounding;
display_bump_depth=outer_upper_depth;
display_bump_offset=[-display_bump_width+outer_upper_rounding+display_bump_rounding,0,10];
display_bump_hollow_offset=[display_bump_offset[0]+global_thickness,display_bump_offset[1]-global_nudge,display_bump_offset[2]+global_thickness];
usbc_bump_rounding=0.1;
usbc_bump_height=4.5;
usbc_bump_width=0.25+outer_upper_rounding+usbc_bump_rounding;
usbc_bump_depth=outer_upper_depth;
usbc_bump_offset=[outer_upper_width-outer_upper_rounding-usbc_bump_rounding,0,7.5];
usbc_bump_hollow_offset=[usbc_bump_offset[0]+(global_thickness*0),usbc_bump_offset[1]-global_nudge,usbc_bump_offset[2]+global_thickness]; //(global_thickness*0) to make is 2x thickness
slider_panel_width=2;
slider_panel_depth=0.4;
slider_panel_height=2;
slider_track_width=0.5;
slider_offset=[outer_upper_width,-(slider_panel_width+(2*slider_track_width))/2,usbc_bump_offset[2]+global_thickness];
screwhole_radius=0.22/2;
screwhole_support_radius=screwhole_radius+global_thickness;
screwhole_nudge=global_nudge;
screwhole_offsets=[ //lateral offsets are to center of screwholes
  [0.5,0,0.5],
  [1.5,0,12.5],
  [9.5,0,12.5],
  [9.5,0,5.5],
];
//holepeg_support_height=outer_upper_depth; //TODO make dependant on location
holepeg_peg_height=global_pcb_thickness;
holepeg_peg_radius=0.1;
holepeg_support_radius=0.2;
holepeg_offsets=[ //lateral offsets are to center of screwholes
  [3,0,0.5],
  [4.5,0,12.5],
  [4.2,0,5.5],
  [7.5,0,5.5],
];

//slider
translate(slider_offset)
rotate(90,[0,0,1])
slider(slider_panel_width,slider_panel_depth,slider_panel_height,slider_track_width);

//front piece
translate([50,0,0]) //comment out line
color("yellow")
difference () {
    union () {
      //main shell upper shelf
      translate([0,0,outer_lower_height])
      roundedcube([outer_upper_width, outer_upper_depth, outer_upper_height], false, outer_upper_rounding, "y");
      //main shell lower shelf
      roundedcube([outer_lower_width, outer_lower_depth, outer_lower_height], false, outer_lower_rounding, "y"); 
      //main shell upper lower rounded corner bridge
      translate([0,0,outer_lower_height-outer_lower_rounding])
      cube([outer_lower_width, outer_lower_depth, outer_upper_rounding+outer_lower_rounding],false);
      //keyboard_bump
      translate(keyboard_bump_offset)
      roundedcube([keyboard_bump_width, outer_lower_depth, keyboard_bump_height], false, keyboard_bump_rounding, "ymax");
      //display bump
      translate(display_bump_offset)
      roundedcube([display_bump_width, outer_upper_depth, display_bump_height], false, display_bump_rounding, "ymax");
      //usbc bump
      translate(usbc_bump_offset)
      roundedcube([usbc_bump_width, outer_upper_depth, usbc_bump_height], false, usbc_bump_rounding, "ymax");
    }
    //main shell upper shelf hollow
    translate([0,0,outer_lower_height])
    translate([global_thickness,-global_nudge,global_thickness]) 
    roundedcube([outer_upper_width-(global_thickness*2), outer_upper_depth-global_thickness, outer_upper_height-(global_thickness*2)], false, outer_upper_rounding, "y");
    //main shell lower shelf hollow
    translate([global_thickness,-global_nudge,global_thickness]) 
    roundedcube([outer_lower_width-(global_thickness*2), outer_lower_depth-global_thickness, outer_lower_height-(global_thickness*2)], false, outer_lower_rounding, "y");
    //main shell upper lower rounded corner bridge hollow
    translate([0,0,outer_lower_height-(2*outer_lower_rounding)])
    translate([global_thickness,-global_nudge,0]) 
    cube([outer_lower_width-(global_thickness*2), outer_lower_depth-global_thickness, 2*(outer_upper_rounding+outer_lower_rounding)],false);
    //keyboard bump hollow
    translate(keyboard_bump_hollow_offset)
    translate([-global_thickness,0,0])
    roundedcube([keyboard_bump_width-global_thickness, outer_lower_depth-(global_thickness), keyboard_bump_height-(2*global_thickness)], false, keyboard_bump_rounding, "ymax");
    //display bump hollow
    translate(display_bump_hollow_offset)
    roundedcube([display_bump_width-(global_thickness)+global_nudge, outer_upper_depth-(global_thickness), display_bump_height-(2*global_thickness)], false, display_bump_rounding, "ymax");
    //usbc bump hollow
    translate(usbc_bump_hollow_offset)
    roundedcube([usbc_bump_width-(global_thickness), outer_upper_depth-(global_thickness), usbc_bump_height-(2*global_thickness)], false, usbc_bump_rounding, "ymax");
    //Keyboard hole
    translate(keyboard_offset) 
    roundedcube([keyboard_width, outer_lower_depth*2, keyboard_height], false, keyboard_rounding, "y");
    //Mouse nav hole
    translate(mouse_nav_offset) 
    roundedcube([mouse_nav_width, outer_lower_depth*2, mouse_nav_height], false, mouse_nav_rounding, "y");
    //Mouse left button hole
    translate(mouse_left_offset) 
    roundedcube([mouse_left_width, outer_lower_depth*2, mouse_left_height], false, mouse_left_rounding, "y");
    //Mouse right button hole
    translate(mouse_right_offset) 
    roundedcube([mouse_right_width, outer_lower_depth*2, mouse_right_height], false, mouse_right_rounding, "y");
    //Display hole
    translate(display_offset) 
    cube([display_width, outer_upper_depth*2, display_height], false);
    //TODO add slider
}

//front screwholes
color("red")
for (i = [ 0 : len(screwhole_offsets)-1 ]) {
  if (holepeg_offsets[i][2]<outer_lower_height) {
    screwhole_support_height=outer_lower_depth;
    screwhole_height=screwhole_support_height-(global_thickness);
    translate(screwhole_offsets[i])
    screwhole(screwhole_support_height-global_nudge, screwhole_height, screwhole_support_radius, screwhole_radius, screwhole_nudge);
  } else {
    screwhole_support_height=outer_upper_depth;
    screwhole_height=screwhole_support_height-(global_thickness*4);
    translate(screwhole_offsets[i])
    screwhole(screwhole_support_height-global_nudge, screwhole_height, screwhole_support_radius, screwhole_radius, screwhole_nudge);
  }
}
//front holepegs
color("orange")
for (i = [ 0 : len(holepeg_offsets)-1 ]) {
  if (holepeg_offsets[i][2]<outer_lower_height) {
    holepeg_support_height=outer_lower_depth;
    translate(holepeg_offsets[i])
    translate([0,-holepeg_peg_height,0])
    holepeg(holepeg_support_height, holepeg_peg_height, holepeg_support_radius, holepeg_peg_radius);
  } else {
    holepeg_support_height=outer_upper_depth;
    translate(holepeg_offsets[i])
    translate([0,-holepeg_peg_height,0])
    holepeg(holepeg_support_height, holepeg_peg_height, holepeg_support_radius, holepeg_peg_radius);
  }
}






outer_rear_depth=2;
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

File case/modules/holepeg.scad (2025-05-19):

module holepeg(support_height, peg_height, support_radius, peg_radius){
  rotate(90,[-1,0,0])
  union () {
    cylinder(h=peg_height, r1=peg_radius, r2=peg_radius, center=false, $fn=256);
    translate([0,0,peg_height])
    cylinder(h=support_height, r1=support_radius, r2=support_radius, center=false, $fn=256);
  }
}

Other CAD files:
case/modules/screwhole.scad
case/modules/roundedcube.scad
case/modules/slider.scad

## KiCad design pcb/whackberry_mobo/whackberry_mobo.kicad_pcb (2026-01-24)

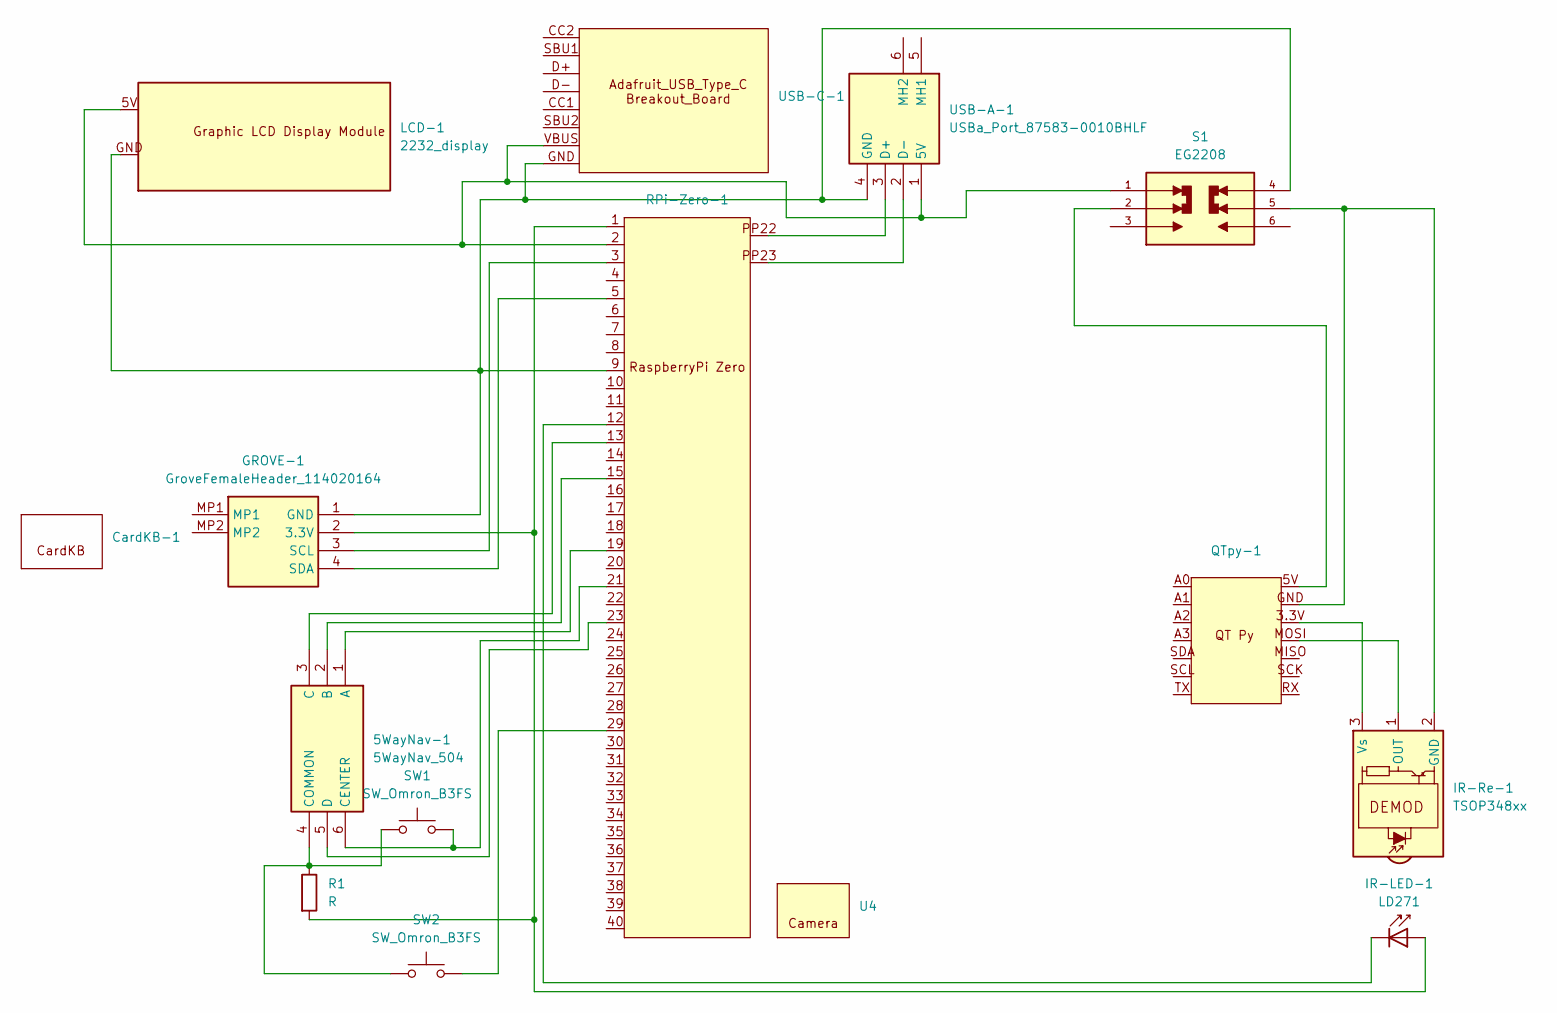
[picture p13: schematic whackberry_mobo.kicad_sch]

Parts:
5WayNav-1: 5WayNav_504; Mouser Part Number 485-504
CardKB-1: CardKB
GROVE-1: GroveFemaleHeader_114020164; Mouser Part Number 713-114020164
IR-LED-1: LD271; LED_D5.0mm_IRGrey
IR-Re-1: TSOP348xx; Vishay_MOLD-3Pin
LCD-1: 2232_display; Display_MODULE_2232; PARTREV N/A
QTpy-1: QT_Py
R1: R; R_Axial_DIN0207_L6.3mm_D2.5mm_P10.16mm_Horizontal
RPi-Zero-1: Modified_Raspberry_Pi_Zero_Socketed_THT_FaceDown_MountingHo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
S1: EG2208; SW_EG2208; PARTREV C
SW1, SW2: SW_Omron_B3FS; SW_TH_Tactile_Omron_B3F-10xx
U4: Camera
USB-A-1: USBa_Port_87583-0010BHLF; USBa_Port_875830010BHLF; Manufacturer_Part_Number 87583-0010BHLF
USB-C-1: Adafruit_USB_Type_C_Breakout_Board

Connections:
unnamed: 5WayNav-1.1 (A), RPi-Zero-1.19
unnamed: 5WayNav-1.2 (B), RPi-Zero-1.15
unnamed: 5WayNav-1.3 (C), RPi-Zero-1.13
unnamed: 5WayNav-1.6 (CENTER), RPi-Zero-1.21, SW1.2
unnamed: 5WayNav-1.4 (COMMON), R1.1, SW1.1, SW2.1
unnamed: 5WayNav-1.5 (D), RPi-Zero-1.23
unnamed: GROVE-1.2 (3.3V), IR-LED-1.2 (A), R1.2, RPi-Zero-1.1
unnamed: GROVE-1.1 (GND), LCD-1.GND, RPi-Zero-1.9, S1.4, USB-A-1.4 (GND), USB-C-1.GND
unnamed: GROVE-1.3 (SCL), RPi-Zero-1.3
unnamed: GROVE-1.4 (SDA), RPi-Zero-1.5
unnamed: IR-LED-1.1 (K), RPi-Zero-1.12
unnamed: IR-Re-1.2 (GND), QTpy-1.GND, S1.5
unnamed: IR-Re-1.1 (OUT), QTpy-1.MOSI
unnamed: IR-Re-1.3 (Vs), QTpy-1.3.3V
unnamed: QTpy-1.5V, S1.2
unnamed: RPi-Zero-1.29, SW2.2
unnamed: LCD-1.5V, RPi-Zero-1.2, S1.1, USB-A-1.1 (5V), USB-C-1.VBUS
unnamed: RPi-Zero-1.PP22, USB-A-1.3 (D+)
unnamed: RPi-Zero-1.PP23, USB-A-1.2 (D-)

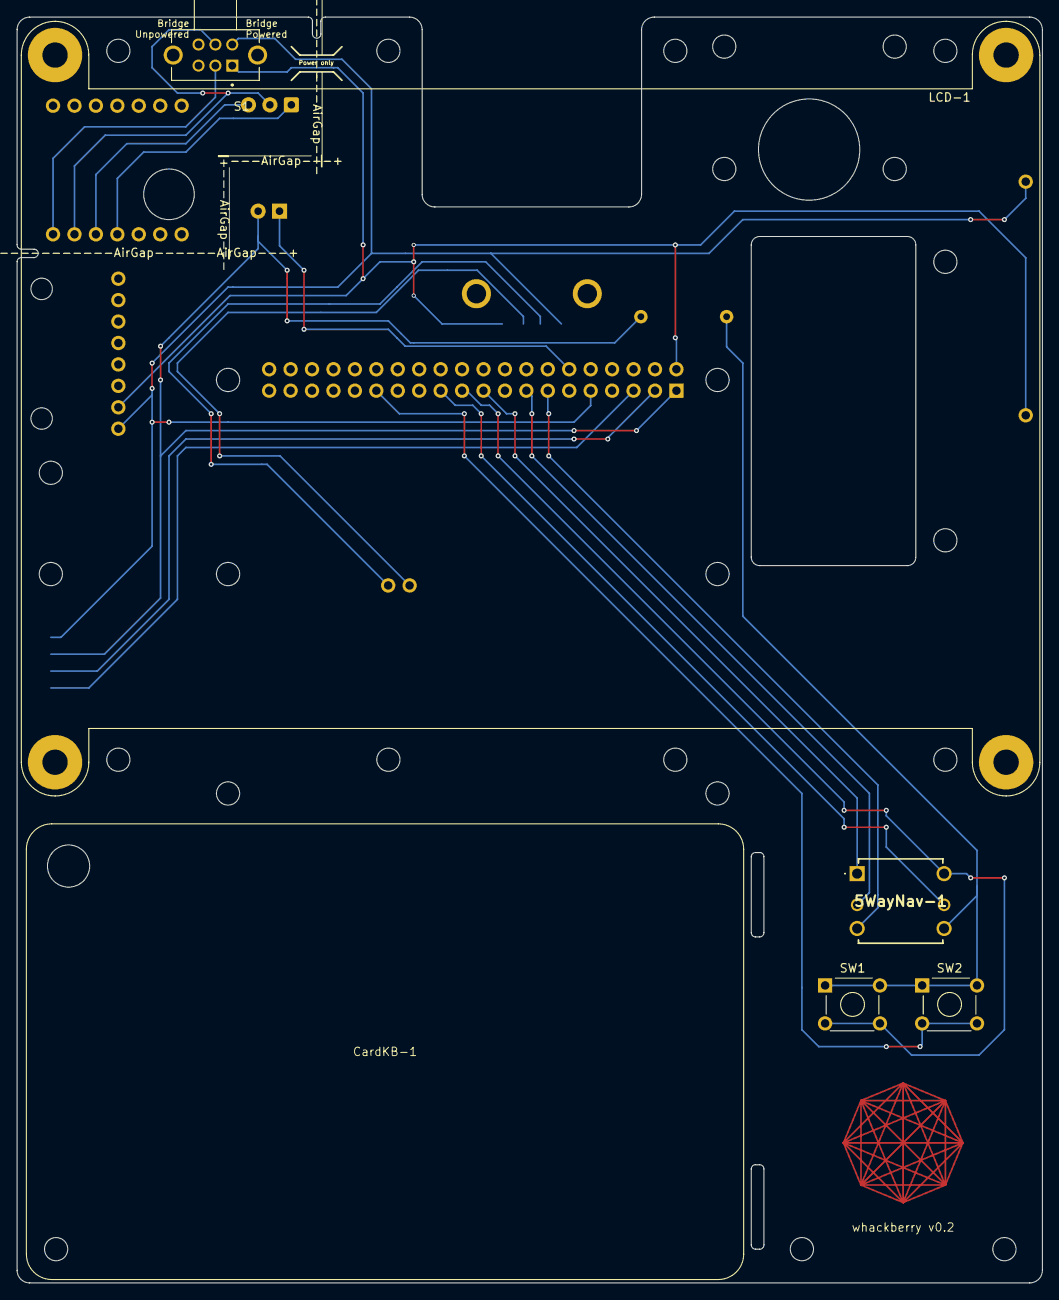
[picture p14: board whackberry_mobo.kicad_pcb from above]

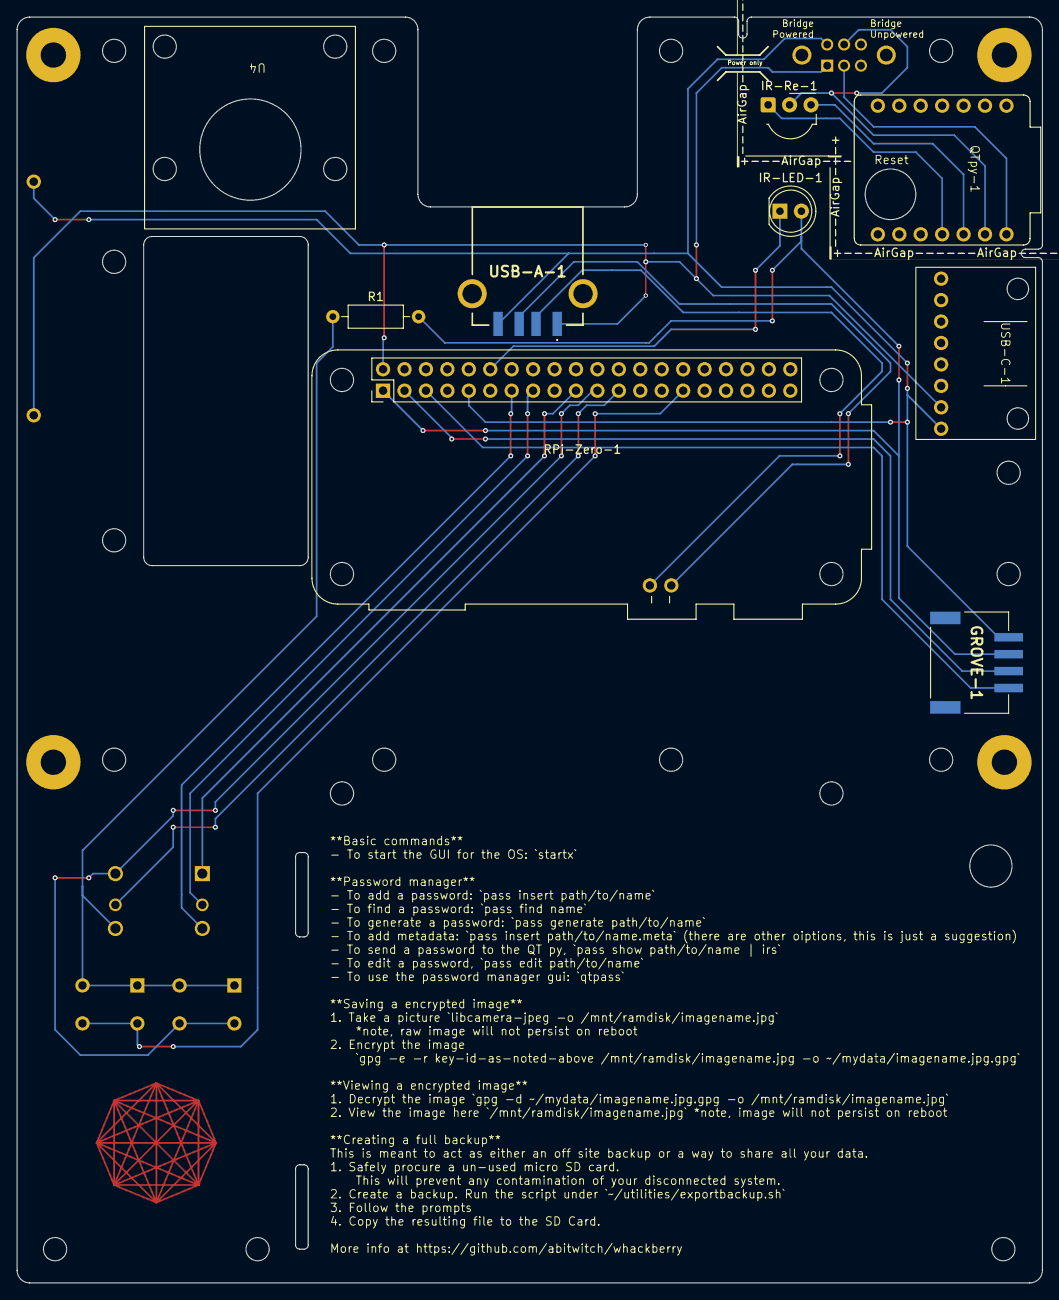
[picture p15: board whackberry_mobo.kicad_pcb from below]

Board: 2 copper layers, 121.5 x 150.0 mm, 15 parts (9 on the bottom side), 19 nets.

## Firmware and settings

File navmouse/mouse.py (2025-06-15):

import time
from pynput.mouse import Button, Controller
import RPi.GPIO as GPIO
GPIO.setmode(GPIO.BOARD)
time_wait=0.1
max_speed=25 #pixels per time wait
leftPin=15
rightPin=23
upPin=19
downPin=13
centerPin=21
rightclickPin=29
GPIO.setup(leftPin, GPIO.IN, pull_up_down=GPIO.PUD_DOWN)
GPIO.setup(rightPin, GPIO.IN, pull_up_down=GPIO.PUD_DOWN)
GPIO.setup(upPin, GPIO.IN, pull_up_down=GPIO.PUD_DOWN)
GPIO.setup(downPin, GPIO.IN, pull_up_down=GPIO.PUD_DOWN)
GPIO.setup(centerPin, GPIO.IN, pull_up_down=GPIO.PUD_DOWN)
GPIO.setup(rightclickPin, GPIO.IN, pull_up_down=GPIO.PUD_DOWN)

centerPin_prevval=GPIO.input(centerPin)==GPIO.HIGH
rightclick_prevval=GPIO.input(rightclickPin)==GPIO.HIGH
mouseReady=False
moving_streak=0
prevInput=0
while True:
  if not mouseReady:
    try:
      mouse=Controller()
      mouseReady=True
    except:
      time.sleep(2)
      continue
  moving=False
  pixels_to_move=1+min(max_speed,int(moving_streak*time_wait*2))
  if GPIO.input(leftPin)==GPIO.HIGH:
    mouse.move(-pixels_to_move,0)
    moving=True
  if GPIO.input(rightPin)==GPIO.HIGH:
    mouse.move(pixels_to_move,0)
    moving=True
  if GPIO.input(upPin)==GPIO.HIGH:
    mouse.move(0,-pixels_to_move)
    moving=True
  if GPIO.input(downPin)==GPIO.HIGH:
    mouse.move(0,pixels_to_move)
    moving=True
  if moving:
    moving_streak+=1
  else:
    moving_streak=0
  centerPin_curval=GPIO.input(centerPin)==GPIO.HIGH
  if centerPin_curval!=centerPin_prevval:
    centerPin_prevval=centerPin_curval
    if centerPin_curval:
      mouse.click(Button.left)
  rightclickPin_curval=GPIO.input(rightclickPin)==GPIO.HIGH
  if rightclickPin_curval!=rightclick_prevval:
    rightclick_prevval=rightclickPin_curval
    if rightclick_prevval:
      mouse.click(Button.right)
  time.sleep(time_wait)
 
 


 
 

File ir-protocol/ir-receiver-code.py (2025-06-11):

#Pico IR reciever
import board
import pulseio
import time
import neopixel
import usb_hid
from adafruit_hid.keyboard import Keyboard
from adafruit_hid.keyboard_layout_us import KeyboardLayoutUS

#Encryption params
crypt_enctrypred=True
crypt_key_size=512
crypt_max_message_len=int(crypt_key_size/8)
if crypt_enctrypred:
  import adafruit_rsa
  import json
  with open("privatekey.json","r") as f:
    pk_json=json.loads(f.read())
  private_key=adafruit_rsa.key.PrivateKey(pk_json["n"],pk_json["e"],pk_json["d"],pk_json["p"],pk_json["q"])

print("start.")
pulses = pulseio.PulseIn(board.MOSI, maxlen=200, idle_state=True)
pixel = neopixel.NeoPixel(board.NEOPIXEL, 1)

kbd = Keyboard(usb_hid.devices)
layout = KeyboardLayoutUS(kbd)

#Allows for n unique pulse lengths
#0: start data stream
#1: end stream
#2: start instructions
#3 to n: data
pulses_per_byte=2
if not pulses_per_byte in [1,2,4,8]:
  raise ValueError(f"Error: can not split a byte into {pulses_per_byte} parts.")
bits_per_pulse=int(8/pulses_per_byte)
n=int(256/pulses_per_byte)+3
pulse_min=1000
pulse_max=(2**16)-pulse_min
#special pulses
start_val=0
end_val=1
inst_val=2
minData_val=3
pulse_increment=(pulse_max-pulse_min)/(n+3)
timeout=10 #how many seconds (or part of) with nothing recieved before timeout
lastrecieved=-1

checksum=checksum_ver=0
byte_part=byte=0
bytedata = bytearray()
stream_status="ready"
packet_status="ready"

def bytearray_to_text(bytedata):   
  return(bytedata.decode("utf-8"))

def decrypt_bytes(bytedata):
  decrypted_bytedata = bytearray()
  c=0
  while c<(len(bytedata)/crypt_max_message_len):
    fromindex=c*crypt_max_message_len
    c+=1
    toindex=min(len(bytedata),c*crypt_max_message_len)
    decrypted_bytedata.extend(adafruit_rsa.decrypt(bytes(bytedata[fromindex:toindex]),private_key))
  return(decrypted_bytedata)
  
def flashcolours(colours,flash_duration,total_duration):
  for i in range(int(total_duration/flash_duration)):
    colour=colours[i%len(colours)]
    pixel.fill(colour)
    time.sleep(flash_duration)
  
def sendKeystrokes(string):
  layout.write(string)
      
while True:
  #set LED
  if packet_status=="receiving":
    pixel.fill((255, 165, 0)) #Orange
  else:
    pixel.fill((0, 0, 0))
  #check for timeout
  if stream_status!="ready" and time.time()-lastrecieved > timeout:
    print("Error: signal timeout.")
    flashcolours([(0, 0, 0),(255, 0, 0)],0.4,2) #Off and Red
    packet_status="ready"
    stream_status="ready"
    checksum=checksum_ver=0
    byte_part=byte=0
    bytedata = bytearray()
    lastrecieved = -1
  #read pulse
  while len(pulses)>0:
    pulse=pulses.popleft()
    pulse_val=(pulse-pulse_min)/pulse_increment
    pulse_val=round(pulse_val)
    if pulse_val in [start_val,end_val,inst_val]:
      lastrecieved=time.time()
    if pulse_val==start_val and stream_status=="ready" and packet_status=="receiving":
      stream_status="datastream"
    elif pulse_val==inst_val:
      if packet_status=="ready":
        stream_status="instruction"
      if packet_status=="receiving":
        stream_status="checksum"
    elif pulse_val==end_val:
      if stream_status=="instruction":
        #prepare new stream
        packet_status="receiving"
        stream_status="ready"
        checksum=checksum_ver=0
        byte_part=byte=0
        bytedata = bytearray()
      elif stream_status=="checksum":
        #finsih current stream
        if checksum==checksum_ver and len(bytedata)!=0:
          if crypt_enctrypred:
            pixel.fill((0,0,255)) #Blue
          else:
            pixel.fill((0, 165, 0)) #Green
          decrypt_failed=False
          if crypt_enctrypred:
            try:
              bytedata=decrypt_bytes(bytedata)    
            except:
              print("Error: decrypt failed. Check public and private keys.")
              flashcolours([(0,0,255),(255, 0, 0)],0.4,2) #Blue and Red
              decrypt_failed=True
          if not decrypt_failed:
            try:
              text=bytearray_to_text(bytedata)
              sendKeystrokes(text)
              pixel.fill((0, 165, 0)) #Green
              time.sleep(1) #keep green and pause any other actions for a short time
            except:
              print("Error: unable to decode or send keys. Check input text.")
              flashcolours([(255, 0,165),(255, 0, 0)],0.4,2) #Pink and Red
        else:
          flashcolours([(255, 165, 0),(255, 0, 0)],0.4,2) #Orange and Red
          print("Error: bad checksum, exiting data stream.")        
        packet_status="ready"
        stream_status="ready"
        checksum=checksum_ver=0
        byte_part=byte=0
        bytedata = bytearray()
        lastrecieved = -1
      else:
        #prepare for new packet
        stream_status="ready"
    elif 0 > pulse_val > n:
      print("Warning: unexpected pulse length, ignoring pulse.")
    elif stream_status in ["datastream","checksum"] and packet_status=="receiving":
      pulse_val-=3  #for the 3 special values
      byte+=pulse_val<<(bits_per_pulse*byte_part)
      byte_part+=1
      if byte_part==pulses_per_byte:
        if stream_status=="checksum":
          checksum_ver=byte
        if stream_status=="datastream" and byte in range(0,256):
          bytedata.append(byte)
          checksum=(checksum+byte)%256
        byte_part=byte=0
    else:
      pass #this is where any unexpected values or padding values used to buffer packets will end up. They can be ignored.

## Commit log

2025-04-12 starting kicad project for pcb
    [motherboard.kicad_pcb, motherboard.kicad_sch]
2025-04-16 adding kicad project
    [motherboard.kicad_sch, whackberry_mobo.kicad_pcb, whackberry_mobo.kicad_sch]
2025-04-18 more kicad work
    [whackberry_mobo.kicad_sch]
2025-04-18 another kicad work save
    [whackberry_mobo.kicad_sch]
2025-04-18 adding last batch of symbols and footprints in KiCad
    [whackberry_mobo.kicad_sch]
2025-04-19 placing parts on PCB
    [whackberry_mobo.kicad_pcb, whackberry_mobo.kicad_sch]
2025-04-19 Ready for tracing PCB
    [whackberry_mobo.kicad_pcb, whackberry_mobo.kicad_sch]
2025-04-19 More changes before tracing PCB
    [whackberry_mobo.kicad_pcb]
2025-04-19 adding gerber files
    [whackberry_mobo-B_Cu.gbr, whackberry_mobo-B_Mask.gbr, whackberry_mobo-B_Paste.gbr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]
2025-04-20 adding images of PCB
    [whackberry_mobo.kicad_sch]
2025-04-30 new pbc changes, fixes to ir-receiver, start on wallet maker
    [ir-receiver-code.py]
2025-05-03 fixing mapping mouse pins
    [mouse.py]
2025-05-03 starting work on case
    [FrontPiece.scad, roundedcube.scad]
2025-05-04 case work
    [FrontPiece.scad]
2025-05-06 case work, adding bump outs
    [FrontPiece.scad]
2025-05-07 case work, building slider
    [FrontPiece.scad, Slider.scad, slider.scad]
2025-05-17 case work and cryptowallet exploration
    [FrontPiece.scad, screwhole.scad, slider.scad]
2025-05-19 more case work
    [FrontPiece.scad, holepeg.scad, screwhole.scad]
2025-05-20 case work. almost done first draft
    [case.scad]
2025-05-23 case work, adding long keybard supports
    [case.scad]
2025-05-29 adding reset button hole
    [case.scad]
2025-05-31 adding cable mgnt and screwdriver slot
    [cable_hook.scad, case.scad]
2025-06-01 casework: adding measurements and camera hole
    [cable_hook.scad, case.scad, screwhole.scad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]
2025-06-01 casework: adding measurements and fixes. Ready for 1st print draft.
    [case.scad]
2025-06-04 adding print layout option to case and minor fixes
    [case.scad]
2025-06-08 improving documenation
    [Slider.scad, case.scad, case.stl]
2025-06-11 fixing time out feature
    [ir-receiver-code.py]
2025-06-12 New PCB changes(v0.2)
    [whackberry_mobo.kicad_pcb]
2025-06-15 fixes from another setup run through
    [mouse.py]
2025-07-08 adding hole to access QTpy Reset button
    [whackberry_mobo.kicad_pcb]
2026-01-24 Adding a control switch for bridge power and other pcb improvements
    [whackberry_mobo-B_Cu.gbr, whackberry_mobo-B_Mask.gbr, whackberry_mobo-B_Paste.gbr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]
2026-02-20 disable mass storage device on rp2040
